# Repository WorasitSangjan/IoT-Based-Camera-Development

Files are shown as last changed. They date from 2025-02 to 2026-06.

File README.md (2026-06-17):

# AGIcam: An Open-Source IoT-Based Camera System for Automated In-Field Phenotyping and Yield Prediction








> **A low-cost, solar-powered IoT platform for high-frequency crop monitoring and yield prediction in wheat breeding trials**

## Repository Structure

```
IoT-based-Camera-Development/
├── 1_Camera_Development/           # Hardware design & 3D models
│   ├── 1_Enclosure_3DModel/        # STL files for 3D printing
│   └── 2_Program_on_RasPi/         # Raspberry Pi software
├── 2_Backend_System/               # Node-RED data pipeline
│   ├── flows.json                  # Complete data flow
│   └── data_transform.js           # Data transformation
├── 3_AGIcam_Dashboard/             # Web interface
│   ├── index.html                  # Homepage
│   ├── dashboardlists.html         # Sensor dashboards
│   └── planthealth.html            # Image galleries
├── 4_Data_Analysis/                # ML models
│   ├── LSTM_TimeSerie_Yield.../    # LSTM implementation
│   └── RandomForest_TimeSerie_.../ # Random Forest models
└── requirements.txt                # Python dependencies
```

## Overview

AGIcam is an open-source Internet of Things (IoT) camera system designed for automated in-field phenotyping and yield prediction. Developed at Washington State University's Phenomics Lab, this platform enables continuous, high-frequency monitoring essential for capturing rapid phenological transitions and dynamic crop responses in breeding programs.

AGIcam Field Deployment

*Figure 1: AGIcam sensor system deployed in a winter wheat breeding trial during the 2022 growing season*

### Key Features

- **Solar-Powered Autonomy**: 6W solar panel with 6,400 mAh battery for season-long operation
- **Wireless Connectivity**: 4G LTE and Wi-Fi for real-time data transmission
- **Dual Camera System**: Synchronized RGB and NoIR imaging (3x daily capture-Adjustable depend on User's requirement)
- **Edge Computing**: On-device vegetation index calculation for 7 VIs
- **Cloud Integration with MING Stack**: Automated data transfer from Node-RED MQTT to InfluxDB with Grafana visualization
- **Low Cost**: $150-200 per sensor unit

## System Architecture

AGIcam System Architecture

*Figure 2: System architecture of the AGIcam platform, illustrating its core components*

The AGIcam platform consists of four main components:

1. **[Hardware Development](1_Camera_Development/)** - Physical sensor design and 3D enclosures
2. **[Backend System](2_Backend_System/)** - Node-RED data pipeline and cloud integration  
3. **[Web Dashboard](3_AGIcam_Dashboard/)** - Real-time monitoring interface
4. **[Data Analysis](4_Data_Analysis/)** - Machine learning models for yield prediction

## Performance Highlights

### Field Deployment Results (2022 Season)
- **18 sensors** deployed across spring and winter wheat trials
- **85%+ uptime** maintained throughout the growing season
- **Sub-daily monitoring** with 3 imaging sessions per day
- **7 vegetation indices** computed in real-time

### Yield Prediction Accuracy
| Crop Type | Model | RMSE (kg/ha) | Error Rate |
|---|---|---|---|
| Spring Wheat | LSTM | 221.76 | 3.41% |
| Winter Wheat | LSTM | 210.28 | 1.62% |
| Spring Wheat | Random Forest | 544.79 | 8.60% |
| Winter Wheat | Random Forest | 1059.82 | 10.41% |

## Quick Start

### Hardware Requirements
- Raspberry Pi Compute Module 3+ Lite
- Dual Raspberry Pi Camera V2 (RGB + NoIR)
- 6W Solar Panel + 6,400 mAh Battery
- Witty Pi 3 power management
- Custom 3D-printed enclosure

### Software Stack
- **OS**: Raspbian Buster
- **Backend**: Node-RED, Python 3.7+
- **Database**: InfluxDB (time-series)
- **Visualization**: Grafana
- **Cloud**: Microsoft Azure with Bootstrap framework

## Research Applications

### Published Results
Our research demonstrates AGIcam's effectiveness for:
- **Yield prediction** with LSTM achieving 1.62% error
- **Phenological monitoring** during critical growth stages
- **High-throughput phenotyping** in breeding programs
- **Real-time decision support** for crop management

### Citation
If you use AGIcam in your research, please cite:

**Paper**:
```
Sangjan, W., Pukrongta, N., Buchanan, T., Carter, A. H., Pumphrey, M. O., & Sankaran, S. (2026). 
AGIcam: An open-source Internet of Things–based camera system for automated in-field phenotyping and yield prediction. 
The Plant Phenome Journal, 9(1), e70088. https://doi.org/10.1002/ppj2.70088
```



**Dataset**:
```
Sangjan, W., Pukrongta, N., Buchanan, T., Carter, A. H., Pumphrey, M. O., & Sankaran, S. (2025). 
AGIcam Dataset: In-Field IoT Sensor Data for Wheat Phenotyping and Yield Prediction [Data set].
Zenodo. https://doi.org/10.5281/zenodo.17970104
```



## Acknowledgments

This research was funded by:
- USDA-NIFA Competitive Project (Accession #1028108)
- Washington State University Hatch Project (Accession #1014919)
- WSU College of CAHNRS Emerging Research Issues Grant (ERI-20-04)

## Contact

- **Lead Researcher**: Worasit Sangjan - [worasit.sangjan@wsu.edu](mailto:worasit.sangjan@wsu.edu)
- **Principal Investigator**: Dr. Sindhuja Sankaran - [s.sankaran@wsu.edu](mailto:s.sankaran@wsu.edu)
- **Institution**: Washington State University, Phenomics Lab

## License

This project is open source under the [MIT License](LICENSE). See the LICENSE file for details.

---
© 2022 AGIcam - Phenomics Lab|Washington State University

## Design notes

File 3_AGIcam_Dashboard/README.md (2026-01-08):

# AGIcam Dashboard

> Web-based interface for monitoring AGIcam IoT camera sensors in agricultural field trials.

## Folder Structure

```
3_AGIcam_Dashboard/
├── index.html              # Homepage
├── dashboardlists.html     # Main dashboard  
├── planthealth.html        # Image galleries
└── images/
    ├── homepage-screenshort.png       # Homepage
    ├── dashboard-screenshort.png      # NDVI thumbnail
    └── planthealth-screenshort.png    # Plant Images
```

## Overview

The AGIcam Dashboard provides real-time monitoring and historical data access for 18 camera sensors deployed in wheat breeding trials. Built with HTML5 and Bootstrap 5, it offers:

- **Real-time NDVI monitoring** via embedded Grafana dashboards
- **Historical image galleries** from field-deployed cameras  
- **Responsive design** for desktop and mobile access

## Screenshots

### Homepage - Field Deployment View
AGIcam Homepage
*Figure 1: Real AGIcam sensors deployed across wheat breeding trials showing field layout and installation*

### Dashboard - Real-time NDVI Monitoring  
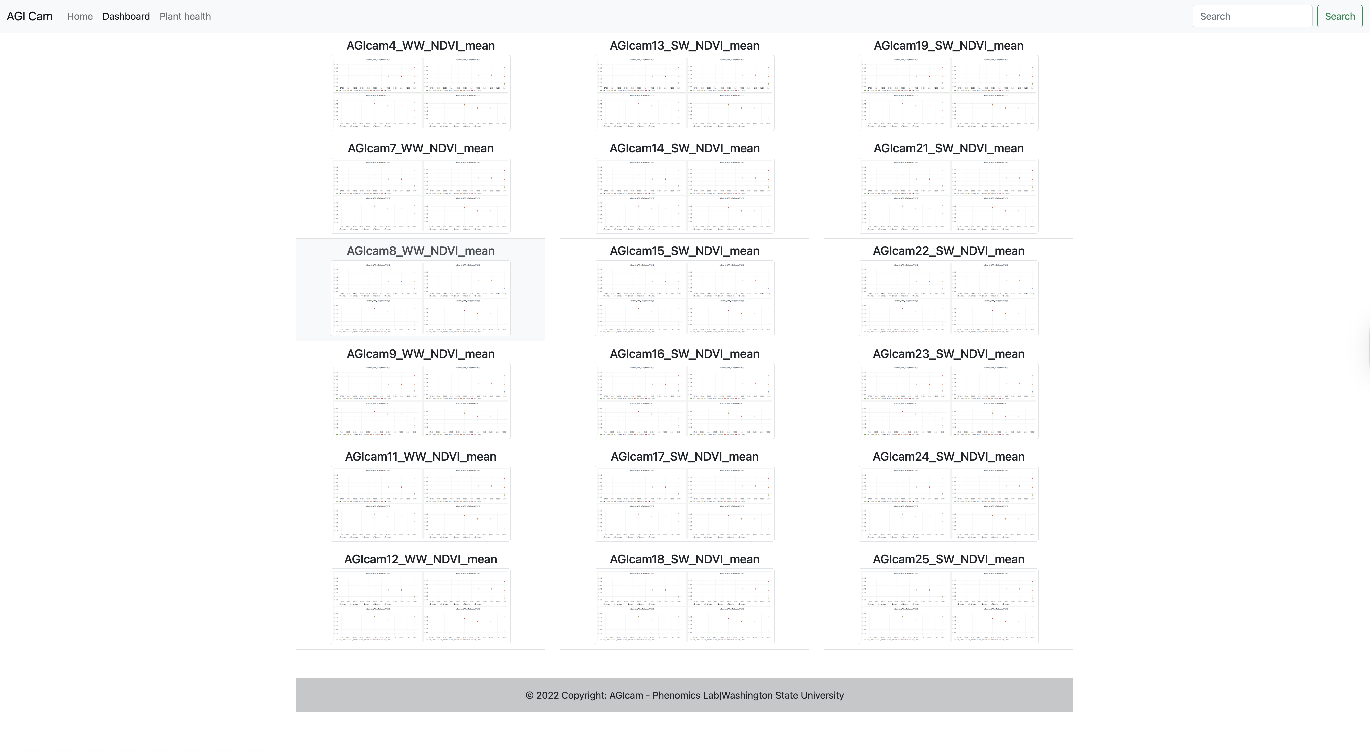
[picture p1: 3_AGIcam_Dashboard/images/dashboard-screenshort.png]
AGIcam Dashboard

*Figure 2: Grid view of all 18 camera sensors with embedded Grafana dashboards for live NDVI monitoring*

### Plant Health - Plant Image Gallery
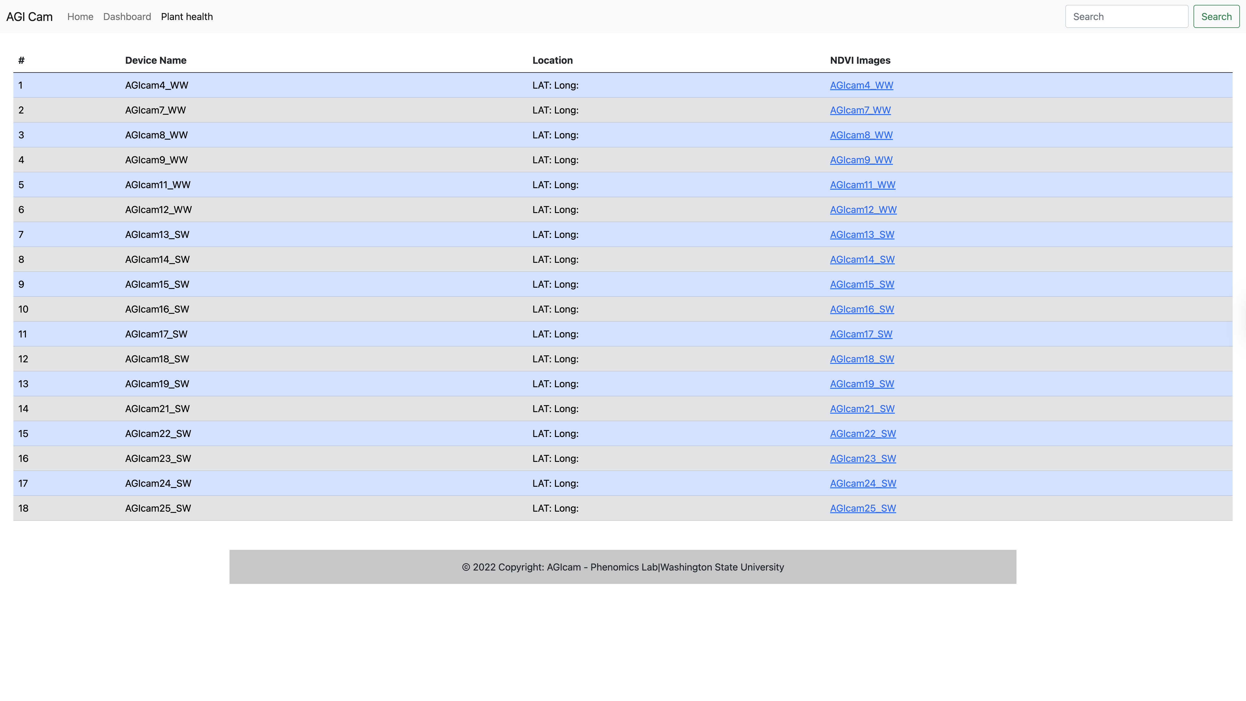
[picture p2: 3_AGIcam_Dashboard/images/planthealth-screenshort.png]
Plant Health Page

*Figure 3: Table interface providing access to plant image galleries for each camera sensor*

## Pages

### 1. Homepage (`index.html`)
Main landing page with AGIcam system overview and navigation to field deployment information.

### 2. Dashboard (`dashboardlists.html`) 
Grid layout displaying all 18 cameras with:
- Real-time NDVI dashboard previews
- Direct links to Grafana dashboards
- Organized by crop type (6 Winter Wheat + 12 Spring Wheat)

### 3. Plant Health (`planthealth.html`)
Table format providing:
- Complete device inventory with IDs and locations
- Direct links to historical image galleries

## Quick Start

1. **Clone repository**
   ```bash
   git clone https://github.com/WorasitSangjan/IoT-based-Camera-Development.git
   cd IoT-based-Camera-Development/4_AGIcam_Dashboard
   ```

2. **Serve files locally**
   ```bash
   python -m http.server 8000
   ```

3. **Open browser**
   ```
   http://localhost:8000
   ```

## External Services

- **Grafana Dashboards**: `Use the link to Grafana on the cloud` - Real-time NDVI data
- **Image Server**: `Use the link to image database on the cloud` - Historical photos
- **Bootstrap CDN**: UI framework and responsive components

## Camera Layout

**18 Total Sensors:**
- **Winter Wheat (6)**: AGIcam4, 7, 8, 9, 11, 12
- **Spring Wheat (12)**: AGIcam13-25 (excluding 20)

**Capture Schedule:** 3 times daily (10:30, 12:00, 13:30)

## Technology Stack

- **Frontend**: HTML5, Bootstrap 5.0.2, JavaScript
- **Visualization**: Embedded Grafana dashboards
- **Responsive**: Mobile-friendly design
- **External APIs**: Real-time data from field sensors

## Features

- **Responsive navigation** with Bootstrap collapse menu
- **Real-time dashboards** embedded via iframes
- **Direct image access** to historical galleries
- **Mobile optimized** for field use
- **External link handling** opens in new tabs

## License

This project is licensed under the MIT License - see the [LICENSE](https://github.com/WorasitSangjan/IoT-based-Camera-Development/blob/main/LICENSE) file for details.

---
© 2022 AGIcam - Phenomics Lab|Washington State University

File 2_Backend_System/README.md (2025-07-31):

# AGIcam Backend Data Pipeline

**Node-RED data pipeline for transferring IoT sensor data from JSON files to InfluxDB time-series database.**

This repository shares the backend code we developed for our AGIcam project, an automated agricultural monitoring system that utilizes IoT cameras and vegetation index analysis.

## Repository Contents

| File | Description | Authors |
|---|---|---|
| **`flows.json`** | Complete Node-RED flow for data transfer pipeline | Nisit Pukrongta and Worasit Sangjan |
| **`data_transform.js`** | JavaScript transformation function example | Nisit Pukrongta and Worasit Sangjan |

## What This Code Does

Our system reads vegetation index data from JSON files and transfers it to InfluxDB for analysis and visualization:

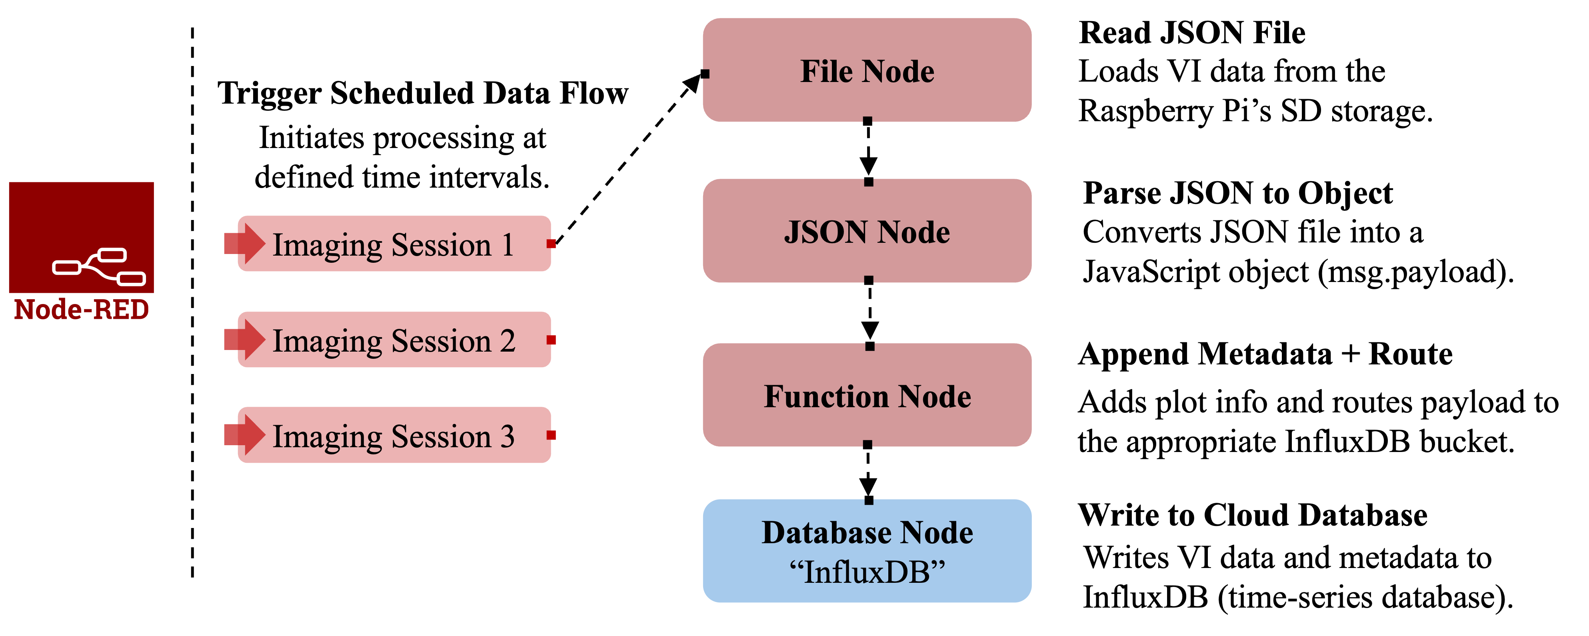
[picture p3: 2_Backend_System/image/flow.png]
AGIcam Data Pipeline


The pipeline automatically processes data at scheduled intervals, transforming nested JSON structures into a time-series database format suitable for analysis and dashboard visualization.

### The Pipeline Flow
1. **Trigger Scheduled Data Flow** - Initiates processing at defined time intervals
2. **Read JSON File** - Loads vegetation index data from Raspberry Pi's SD storage
3. **Parse JSON to Object** - Converts JSON file into JavaScript object (msg.payload)
4. **Function Node** - Transforms data structure and adds metadata + routing
5. **Database Node** - Writes VI data and metadata to the InfluxDB time-series database

## What You Can Adapt for Your Project

### For IoT Data Transfer Projects
- **Node-RED flow structure** - Basic pipeline pattern for file → database transfer
- **JSON to InfluxDB transformation** - Converting nested data to time-series format
- **Multi-sensor data handling** - Processing data from multiple IoT devices
- **Automated scheduling** - Triggered data processing workflow

### Customizable Components
- **Input source**: Change from JSON files to MQTT, HTTP, or other data sources
- **Data transformation**: Modify the JavaScript function for your data structure
- **Output database**: Replace InfluxDB with PostgreSQL, MongoDB, etc.
- **Number of sensors**: Scale up/down for your sensor network

## Quick Setup

1. **Import the flow**: Copy `flows.json` content into Node-RED
2. **Modify data paths**: Update file paths and database connections for your setup
3. **Customize transformation**: Edit the function node using `data-transform.js` as reference
4. **Deploy and test**: Run the pipeline with your data

## Our Data Structure Example

**Input (JSON file)**:
```json
{
  "rep1": {
    "vr1_1": {
      "timestamp": "2022-05-15T12:00:00Z",
      "mean": 0.85,
      "median": 0.84,
      "std": 0.12,
      "max": 0.95
    }
  }
}
```

**Output (InfluxDB)**:
```javascript
{
  measurement: "vr1_1",
  fields: { mean: 0.85, median: 0.84, std: 0.12, max: 0.95 },
  tags: { plot: "rep1" },
  timestamp: new Date()
}
```

## Technology Stack

- **Node-RED**: Visual programming for IoT data flows
- **InfluxDB 1.x**: Time-series database for sensor data
- **JavaScript**: Data transformation logic

## License

This project is licensed under the MIT License - see the [LICENSE](https://github.com/WorasitSangjan/IoT-based-Camera-Development/blob/main/LICENSE) file for details.

---
© 2022 AGIcam - Phenomics Lab|Washington State University

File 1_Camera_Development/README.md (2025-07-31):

# AGIcam Hardware
This repository contains the hardware and code for the AGIcam IoT-based camera system, designed for automated field phenotyping.

## Branch Contents

### 1. **1_Camera_Development**
Hardware design components for the physical camera system:

## Hardware Components

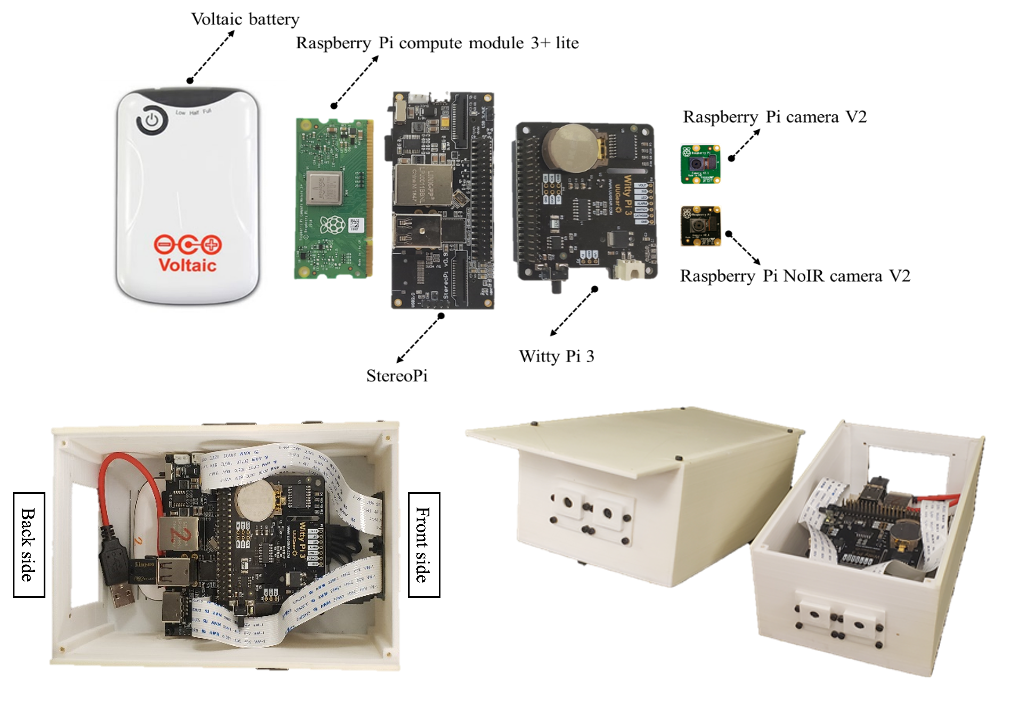
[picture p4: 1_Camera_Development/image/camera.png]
AGIcam Hardware Assembly


The 3D printed enclosure system houses the following components:
- Raspberry Pi Compute Module 3+ Lite (main processing unit)
- Dual Raspberry Pi Camera V2 modules (RGB and NoIR)
- Witty Pi 3 power management board
- Voltaic battery system
- StereoPi board for dual camera control

**1_Enclosure_3DModel/** - 3D printable enclosure files:
- `CameraCOVER.stl` - STL file for camera protective cover
- `HousingCOVER.stl` - STL file for main enclosure lid  
- `InstallFLANGE.stl` - STL file for mounting flange
- `Sensor_housing.stl` - STL file for primary electronics housing

### 2. **2_Program_on_RasPi**
Software components that run on Raspberry Pi to automatically capture images and extract the plant traits:

**Documentation Files:**
- `0_crontab_docs.md` - Markdown file with scheduled task setup instructions
- `0_rustdesk_docs.md` - Markdown file with remote desktop access guide

**Python Scripts:**
- `1_capture_dual_img.py` - Python script for synchronized RGB/NoIR image capture
- `1_capture_dual_img_original.py` - Python script for synchronized RGB/NoIR image capture (original version)
- `2_extract_ndvi.py` - Python script for vegetation index calculation

## Python Requirements

**Recommended Python Version:** 3.7+

**Required Libraries:**
```bash
# For image capture scripts
pip3 install picamera2

# For NDVI processing
pip3 install opencv-python numpy
```

**Library Details:**
- `picamera2` - Raspberry Pi camera interface
- `opencv-python` (cv2) - Image processing
- `numpy` - Numerical operations
- Built-in libraries: `os`, `time`, `datetime`, `json`, `statistics`

## License

This project is licensed under the MIT License - see the [LICENSE](https://github.com/WorasitSangjan/IoT-based-Camera-Development/blob/main/LICENSE) file for details.

---
© 2022 AGIcam - Phenomics Lab|Washington State University

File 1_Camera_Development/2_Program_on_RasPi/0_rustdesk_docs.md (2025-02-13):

# RustDesk Installation Guide for Raspberry Pi 5

This guide provides step-by-step instructions for installing and configuring RustDesk on a Raspberry Pi 5.

## Table of Contents
- [Basic Installation](#basic-installation)
- [Optional Setup](#optional-setup)
- [Fixed Password Configuration](#fixed-password-configuration)

## Basic Installation

### 1. Download RustDesk
- Visit the [RustDesk official website](https://rustdesk.com/)
- Click "Download" at the top right
- Scroll down to the Linux section
- Select "Debian/Ubuntu (arm64)" to download

### 2. Install RustDesk
```bash
cd ~/Downloads
sudo dpkg -i rustdesk-*.deb   # Replace * with actual version number
```

### 3. Fix Dependencies (If Needed)
If the installation fails due to missing dependencies:
```bash
sudo apt --fix-broken install -y
sudo apt install -y libxdo3 gstreamer1.0-pipewire libayatana-appindicator3-1
sudo dpkg -i rustdesk-*.deb   # Reinstall after fixing dependencies
```

### 4. Launch Application
```bash
rustdesk &
```
The application should now open and display your ID and Password.

## Optional Setup

### Enable Auto-Start on Boot
To configure RustDesk to start automatically when your Raspberry Pi boots:
```bash
sudo systemctl enable rustdesk
sudo systemctl start rustdesk
```

## Fixed Password Configuration

To set up a permanent password for unattended access:

1. Open RustDesk on your Raspberry Pi
2. Locate the three-dot menu (⋮) next to your RustDesk ID
3. Open Settings
4. In the Security section:
   - Enable "Use permanent password"
   - Set your desired permanent password

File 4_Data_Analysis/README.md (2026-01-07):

# Data Analysis




This folder contains the data analysis components for AGIcam's yield prediction pipeline, implementing both Random Forest and Long Short-Term Memory (LSTM) models for wheat yield prediction using time-series vegetation index data.

## Folder Structure

```
4_Data_Analysis/
├── LSTM_TimeSerie_YieldPrediction/     # LSTM model implementation
├── RandomForest_TimeSerie_Yield.../    # Random Forest model implementation
└── README.md                           # This file
```

## Overview

The data analysis pipeline processes time-series vegetation index (VI) data collected by AGIcam sensors to predict grain yield in wheat breeding trials. Two machine learning approaches are implemented:

1. **Random Forest Regression**: Uses Area Under Curve (AUC) features from the VI time series
2. **Long Short-Term Memory (LSTM)**: Processes sequential VI data to capture temporal dependencies

## Data Requirements

### Dataset Availability
**Dataset will be published on Zenodo** - Link will be shared soon

### Input Data Format
- **Time-series VI data**: JSON format with timestamp metadata
- **Vegetation Indices**: Seven VIs computed from RGB/NoIR imagery
  - Chlorophyll Index Green (CIgreen)
  - Enhanced Vegetation Index 2 (EVI2)
  - Green Normalized Difference Vegetation Index (GNDVI)
  - Normalized Difference Vegetation Index (NDVI)
  - Renormalized Difference Vegetation Index (RDVI)
  - Soil Adjusted Vegetation Index (SAVI)
  - Simple Ratio (SR)
- **Ground truth yield data**: Plot-level grain yield measurements
- **Metadata**: Plot IDs, replicate information, phenological stages

### Data Collection Schedule
- **Frequency**: 3 times per day (10:30, 12:00, 13:30)
- **Images per session**: 5 synchronized RGB and NoIR images
- **Season duration**: ~2 months (spring wheat), ~3 months (winter wheat)

## Model Implementations

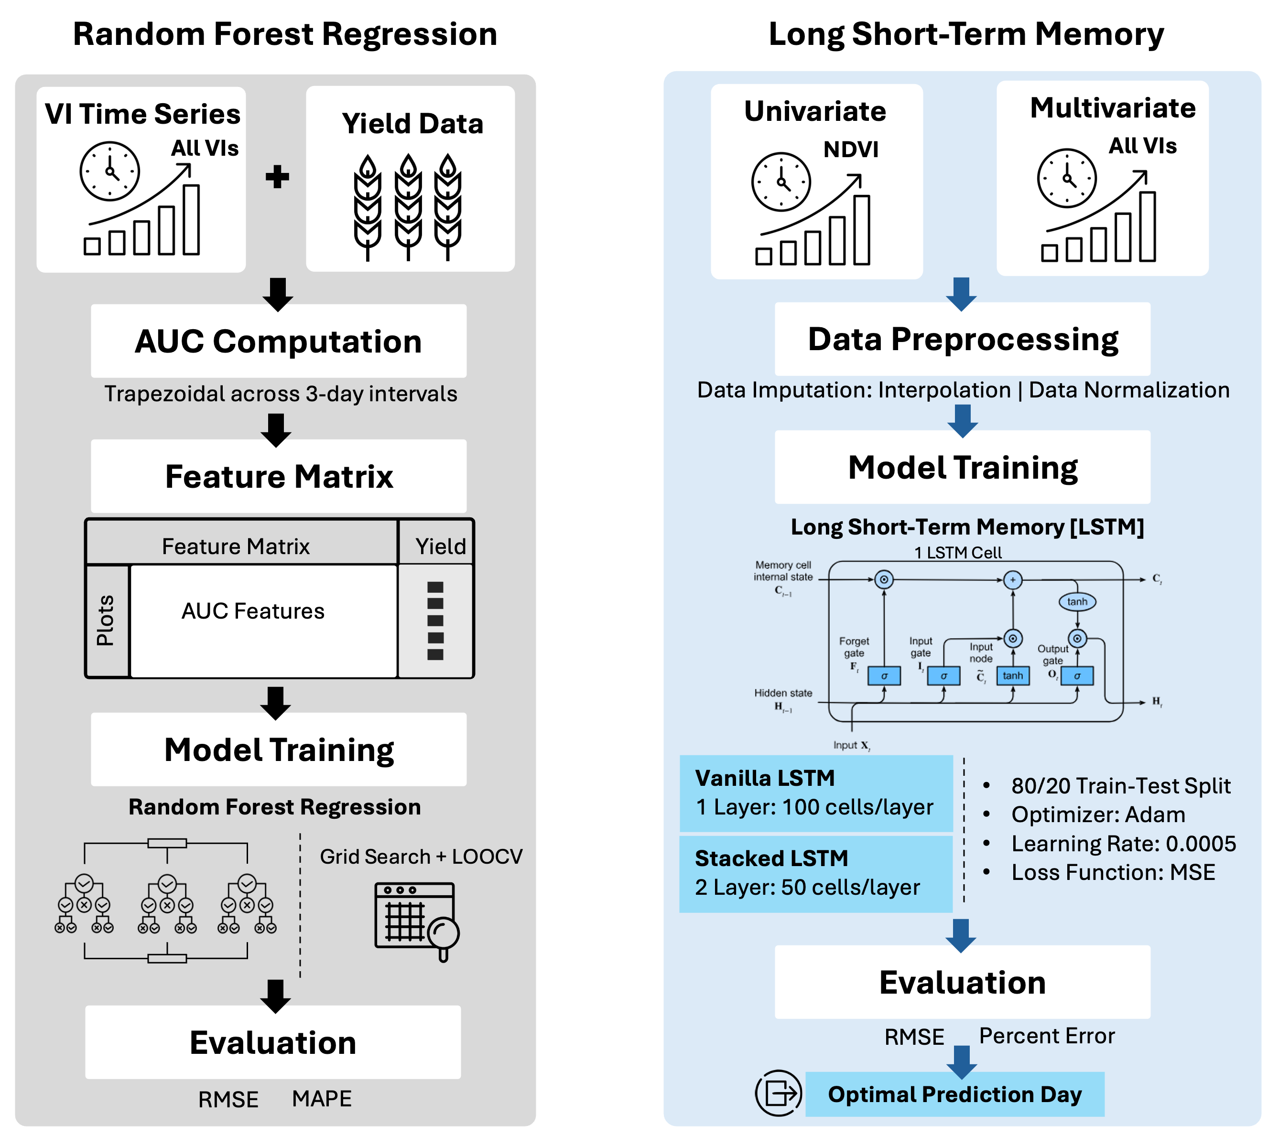
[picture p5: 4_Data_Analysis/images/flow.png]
Machine Learning and Deep Learning Workflow


*Figure 1: Machine learning and deep learning frameworks for yield prediction using time-series vegetation index (VI) data*

### Random Forest Regression

**Approach**: 
- Converts VI time series into Area Under Curve (AUC) features using the trapezoidal rule
- Divides the growing season into temporal windows:
  - Initial 7-day window for early-season variability
  - Non-overlapping 3-day intervals thereafter
  - Results in 19 intervals (spring wheat) and 25 intervals (winter wheat)

**Workflow**:
1. **VI Time Series + Yield Data** → Combined input datasets
2. **AUC Computation** → Trapezoidal integration across 3-day intervals
3. **Feature Matrix** → Structured input for model training
4. **Model Training** → Random Forest with Grid Search + LOOCV optimization
5. **Evaluation** → RMSE and MAPE performance metrics

**Key Features**:
- Uses scikit-learn RandomForestRegressor
- Hyperparameter optimization via grid search with LOOCV
- Feature importance analysis to identify key VIs and time windows
- Performance metrics: RMSE and MAPE

### Long Short-Term Memory (LSTM)

**Approach**:
- Processes sequential VI data to capture temporal dependencies
- Two input configurations: 
  - **Univariate**: NDVI only
  - **Multivariate**: All 7 VIs
- Per-plot evaluation identifying optimal prediction day for each plot

**Workflow**:
1. **Data Preprocessing** → Interpolation and normalization
2. **Model Training** → LSTM architectures with temporal sequence processing
3. **Evaluation** → RMSE, Percent Error, and Optimal Prediction Day identification

**Architectures**:
- **Vanilla LSTM**: 1 Layer, 100 cells/layer
- **Stacked LSTM**: 2 Layers, 50 cells/layer

**Implementation Details**:
- Framework: TensorFlow
- 80/20 Train-Test Split
- Optimizer: Adam (learning rate = 0.0005)
- Loss function: Mean Squared Error (MSE)
- Regularization: L2 regularization, dropout (0.2)

## Dependencies

### Python Libraries
- **scikit-learn**: Random Forest implementation and evaluation metrics
- **TensorFlow**: LSTM model development and training
- **pandas**: Data manipulation and preprocessing
- **numpy**: Numerical computations
- **matplotlib/seaborn**: Data visualization
- **scipy**: Statistical functions (trapezoidal rule for AUC)

## License

This project is licensed under the MIT License - see the [LICENSE](https://github.com/WorasitSangjan/IoT-based-Camera-Development/blob/main/LICENSE) file for details.

---
© 2022 AGIcam - Phenomics Lab|Washington State University

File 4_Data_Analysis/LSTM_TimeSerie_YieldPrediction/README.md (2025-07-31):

# LSTM Time Series Yield Prediction

A deep learning system for predicting crop yields using LSTM neural networks with time series data from AGIcam.

This project implements Long Short-Term Memory (LSTM) neural networks to predict wheat crop yields based on:
- **Vegetation Indices**: NDVI, EVI2, SAVI, GNDVI, etc.
- **Time Series Data**: Daily measurements throughout growing season

## Project Structure

```
LSTM_TimeSerie_YieldPrediction/
├── DataStructures/           # Core data models
│   ├── conditions_state.py   # Weather/environmental data
│   ├── data_point.py         # Daily measurement point
│   ├── plot.py               # Agricultural plot data
│   └── vi_state.py           # Vegetation indices
├── Helpers/                  # Utility functions
│   ├── interpolator.py       # Missing data interpolation
│   ├── parser.py             # CSV data parsing
│   ├── utility.py            # General utilities
│   └── visualizer.py         # Data visualization
├── data_handler.py           # Main data processing & management
├── lstm_model.py             # LSTM model implementations
├── requirements.txt          # Python dependencies
└── README.md                 # This file
```

## Quick Start

### Prerequisites
```bash
pip install -r requirements.txt
```

## Features

### Data Processing
- **Automatic data interpolation** for missing values
- **Sequence preparation** for LSTM input formatting
- **Train/test splitting** with variety balancing
- **Data normalization** and preprocessing

### LSTM Models
- **VanillaLSTM**: Single-layer LSTM (100 units)
- **StackedLSTM**: Multi-layer LSTM (50+50 units)
- **Customizable architectures** with regularization
- **Early stopping** and model checkpointing

### Analysis Tools
- **Yield prediction** with accuracy metrics
- **Time series visualization** 
- **Correlation analysis** between variables and yield
- **Model performance evaluation**

## 🔧 Model Architecture

### VanillaLSTM
```
Input → Masking → LSTM(100) → BatchNorm → Dropout → Dense(1)
```

### StackedLSTM
```
Input → Masking → LSTM(50) → Dropout → BatchNorm → 
LSTM(50) → Dropout → BatchNorm → Dense(1)
```

## Data Format

The system expects agricultural plot data with:
- **Plot metadata**: variety, location, yield, etc.
- **Time series data**: Daily measurements of:
  - Vegetation indices (NDVI, EVI2, SAVI, etc.)

## Use Cases

- **Precision Agriculture**: Optimize farming decisions
- **Yield Forecasting**: Predict harvest outcomes
- **Research**: Study crop-environment relationships

## Requirements

- Python 3.7+
- TensorFlow 2.x
- NumPy
- Pandas
- Matplotlib
- Scipy
- Colorama

## License

This project is licensed under the MIT License - see the [LICENSE](https://github.com/WorasitSangjan/IoT-based-Camera-Development/blob/main/LICENSE) file for details.

---
© 2022 AGIcam - Phenomics Lab|Washington State University

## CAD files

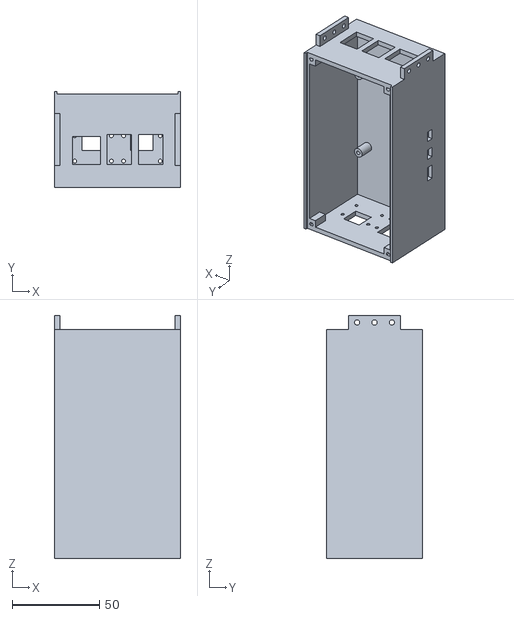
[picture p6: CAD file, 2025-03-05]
1_Camera_Development/1_Enclosure_3DModel/Sensor_housing.stl
72.4 x 55.0 x 139.4

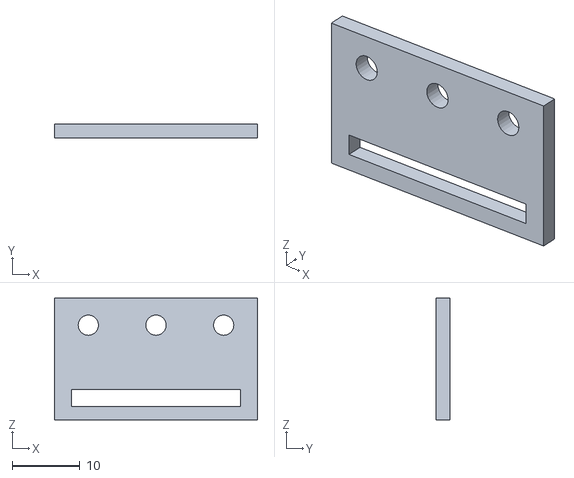
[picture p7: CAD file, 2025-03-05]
1_Camera_Development/1_Enclosure_3DModel/InstallFLANGE.stl
30.0 x 2.00 x 18.0

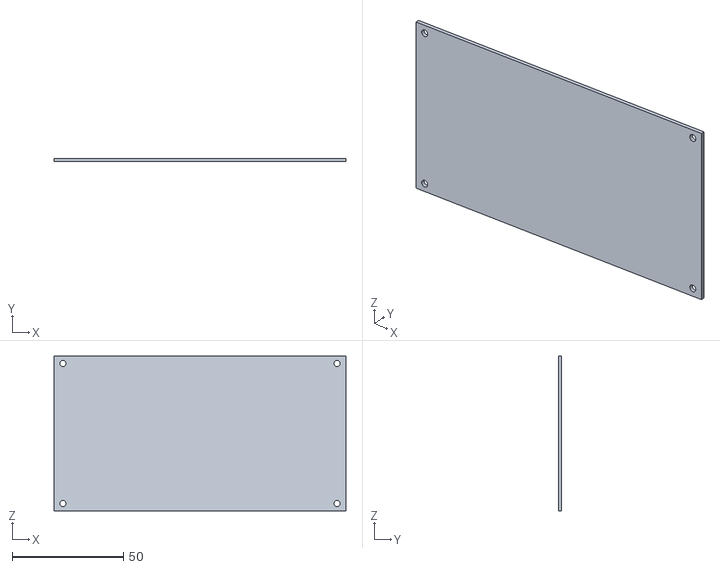
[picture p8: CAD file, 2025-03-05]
1_Camera_Development/1_Enclosure_3DModel/HousingCOVER.stl
131.4 x 1.50 x 69.6

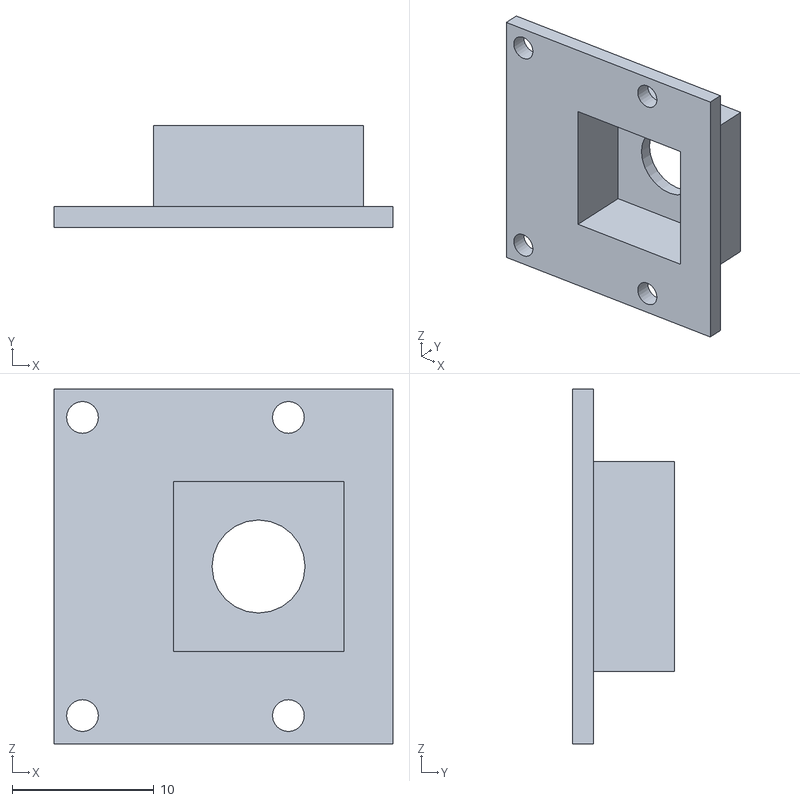
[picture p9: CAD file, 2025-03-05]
1_Camera_Development/1_Enclosure_3DModel/CameraCOVER.stl
23.9 x 7.20 x 25.0

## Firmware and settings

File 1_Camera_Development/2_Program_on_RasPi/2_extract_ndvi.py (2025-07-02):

# Author: Worasit Sangjan
# Date: 8 Febuary 2022

import os
from pathlib import Path
import time
from datetime import datetime
import cv2 
import numpy as np
from statistics import mean
import json


t2 = datetime.now()
# Create a list of data in directory
in_path = '/media/pi/IOT11/image'
in_data = [img for img in os.listdir(in_path) if img.startswith(t2.strftime("%d-%m-%Y_%H"))]

# Image size
i_w = 1280
i_h = 1248

rep = []
replicate = ['rep1', 'rep2', 'rep3', 'rep4', 'rep5']

print('start')
# Loop to extract the vi
for file in in_data:
    img = cv2.imread(os.path.join(in_path, file)) # Read the image 
    img = img[100:900, i_w:2496] # Resize the image
    
    # Solit the color band
    b, g, r = cv2.split(img)
    # Calculate the ndvi
    ndvi = ((1.664*(b.astype(float))) / (0.953*(r.astype(float)))) - 1
    # Create black image for masking
    blank = np.zeros(ndvi.shape[:2], dtype='uint8')
    
    # Mask location on the image
    plot = [[(280, 190), (400, 190), (330, 300), (160, 300)], # !!! change
            [(500, 190), (650, 190), (640, 300), (460, 300)], # !!! change
            [(735, 190), (885, 190), (930, 300), (750, 300)], # !!! change
            [(980, 190), (1105, 190), (1200, 285), (1020, 285)]] # !!! change
    var = ['vr1_1', 'vr2_1', 'vr3_1', 'vr4_1']
    nd = []
 
    for pl in plot:
        # Mask the plot in left side
        pl_m = cv2.fillPoly(blank, np.array([pl]), 255)
        m = cv2.bitwise_and(ndvi, ndvi, mask=pl_m)
        m[m <= 0] = np.nan # Replace zero value to nan
        mean_m = round(np.nanmean(m), 5)
        median_m = round(np.nanmedian(m), 5)
        std_m = round(np.nanstd(m), 5)
        max_m = round(np.nanmax(m), 5)
        p95_m = round(np.nanpercentile(m, 95), 5)
        p90_m = round(np.nanpercentile(m, 90), 5)
        p85_m = round(np.nanpercentile(m, 85), 5)
        timestamp = t2.strftime("%d-%m-%Y_%H-%M-%S")
        # Make dictionary for ndvi of one plot
        data = [timestamp, mean_m, median_m, std_m, max_m, p95_m, p90_m, p85_m]
        header = ['timestamp', 'mean', 'median', 'std', 'max', 'p95', 'p90', 'p85']
        dict_plot = {i:j for i, j in zip(header, data)}
        # Combine ndvi data of all plots in lllllist datatype
        nd.append(dict_plot)
    # Match each ndvi dict with their plot's name
    ndvi_data = dict(zip(var, nd))
    # Combine ndvi of all images
    rep.append(ndvi_data)
# Match each ndvi dict with their plot's name
final_data = dict(zip(replicate, rep))
json_file = open('/home/pi/MScamera/ndvi.json', 'w')
json.dump(final_data, json_file, indent=6)
json_file.close()
print('finish')        

        

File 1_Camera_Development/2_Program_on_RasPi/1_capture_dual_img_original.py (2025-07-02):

# Author: Worasit Sangjan
# Date: 8 Febuary 2022

import os
import time
from datetime import datetime
import picamera
from picamera import PiCamera
import cv2
import numpy as np

# Photo session settings
total_photos = 5             # Number of images to take
countdown = 15               # Interval for count-down timer, seconds
 
# Camera settimgs
cam_width = 1280              # Cam sensor width settings
cam_height = 624              # Cam sensor height settings

# Final image capture settings
scale_ratio = 2

# Camera resolution height must be dividable by 16, and width by 32
cam_width = int((cam_width+31)/32)*32
cam_height = int((cam_height+15)/16)*16

# Buffer for captured image settings
img_width = int (cam_width * scale_ratio)
img_height = int (cam_height * scale_ratio)
capture = np.zeros((img_height, img_width, 4), dtype=np.uint8)

# Initialize the camera
camera = PiCamera(stereo_mode='side-by-side', stereo_decimate=False)
camera.resolution=(cam_width, cam_height)
camera.framerate = 20
camera.hflip = False

# Lets start taking photos! 
counter = 0
t2 = datetime.now()
print ("Starting photo sequence")
for frame in camera.capture_continuous(capture, format="bgra", use_video_port=True, resize=(img_width,img_height)):
    t1 = datetime.now()
    cntdwn_timer = countdown - int ((t1-t2).total_seconds())
    
    # If cowntdown is zero - let's record next image
    if cntdwn_timer == -1:
      counter += 1
      filename = '/media/pi/IOT11/image/'+str(t2.strftime("%d-%m-%Y_%H-%M-%S"))+'_'+str(counter) + '.png'
      img_rotate_180 = cv2.rotate(frame, cv2.ROTATE_180)
      cv2.imwrite(filename, img_rotate_180)
      print (' ['+str(counter)+' of '+str(total_photos)+'] '+filename)
      t2 = datetime.now()
      time.sleep(1)
      cntdwn_timer = 0      # To avoid "-1" timer display 
      next
    
    # Break the program when receiving all images
    if counter == total_photos:
      break

print ("Photo sequence finished")

src_dir = '/media/pi/IOT11/image'
up_img = [img for img in os.listdir(src_dir) if img.startswith(t2.strftime("%d-%m-%Y_%H")) and img.endswith('3.png')]

for img in up_img:
    image = cv2.imread(os.path.join(src_dir, img))
    filename = '/media/pi/IOT11/img_upload/' + str(t2.strftime("%d-%m-%Y_%H-%M-%S"))+'.png'
    cv2.imwrite(filename, image)

print('Finished')

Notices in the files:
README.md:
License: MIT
